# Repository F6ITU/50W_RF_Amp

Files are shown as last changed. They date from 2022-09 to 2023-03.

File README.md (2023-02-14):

# 50W_RF_Amp, Codename Diomedes

Diomedes is a 47 dBm (50W) HF amplifier designed by Manfred XQ6FOD, and intended to be used with any baseband SDR delivering no more than 5 to 10 dBm of  output power between 1 and 54 MHz. 

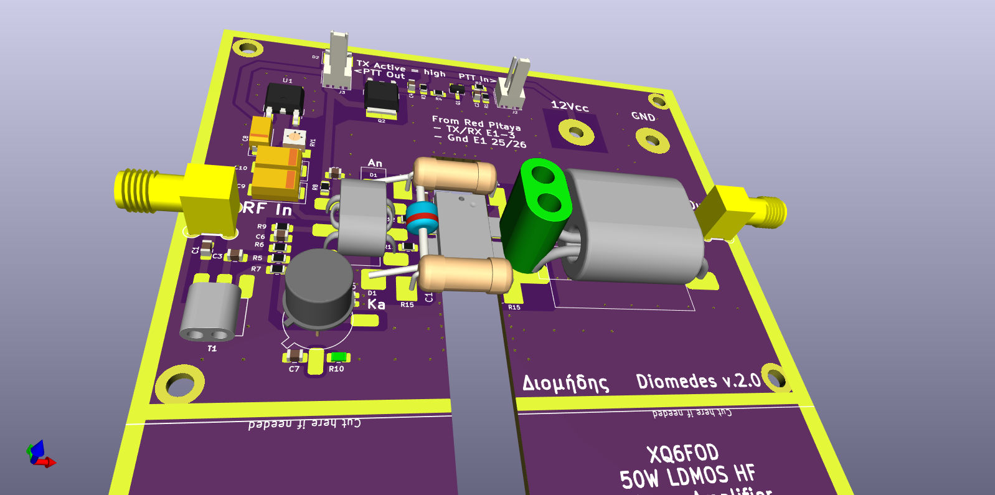
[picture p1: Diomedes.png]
Diomedes, a 50W linear amplifier by XQ6FOD


The original schematic of this project 

https://ludens.cl/Electron/50Wamp/RP50Wampwm.png

as well as the assembly instructions are available at the following URL

https://ludens.cl/Electron/50Wamp/50Wamp.html

This github repository only serves to simplify the work of people who want to build this amplifier. It offers  them the Gerber files and the KiCad implementation of this project.

Thank you, Manfred, for the many developments you’ve done around the Red Pitaya board, and especially for your work on the EER support. It’s a « must read »… at least.

This amplifier is designed to follow a 14 or 16 bit Red Pitaya board or any barefoot DDC/DUC SDR board. It completes the series of devices constituting the Alexiares frontend developed by the OpenHPSDR group

https://wiki.electrolab.fr/Projets:Lab:2017:Peripheriques_Angelia

and replaces advantageously the old and outdated  Pennywhistle linear amplifier 

https://openhpsdr.org/pennywhistle.php

It should be noted that board's dimensions and mounting holes are completely compatible with Pennywhistle physical and mechanical design. In fact, Diomedes has been designed as a substitute amplifier. 
The only major difference is the input allowed power (9 dBm for Diomedes, 27 dBm max for Pennywhistle).

More powerful, more sensitive, less expensive, modern, this final stage uses a tandem of LDMOS transistors. It is perfectly matched with the Alex low pass filter 

https://wiki.electrolab.fr/Projets:Lab:2017:Peripheriques_Angelia#Alexiares_lpf

The code name Diomede was given to this amplifier to match the OpenHPSDR naming scheme. 
Diomedes, hero of the Illiad, was one of the most powerful warrior of the Argian clan, opponent of Apollo the defender of Troy. Apollo is the code name of the very first amplifier and low-pass filter tanddem proposed by the OpenHPSDR 

https://openhpsdr.org/apollo.php

So far, this github project is still under development, as long as the first Diomedes PCB  hasn’t been assembled and tested. Do NOT use these Gerber files for the moment.

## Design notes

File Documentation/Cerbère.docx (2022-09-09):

Cerbère (Κέρϐερος) est le chien tricéphale, gardien des enfers. Ce gardien-là préserve le SDR des démons provenant des secondes, troisièmes et quatrièmes zones de nyquist. C’est un triple filtre passe-bas destiné à tous les transceivers bande de base couvrant de 0,1 à 60 MHz et qui ne possèdent pas déjà ce genre de protection. C’est notamment le cas des cartes Red Pitaya 14 et 16 bits.

Cerbère fait précéder chacune des deux entrées réception (ADC) d’un double filtre Mini Circuits coupant à partir de 50 MHz. Cette cascade garanti une élimination de plus de 70 dB tout signal émis notamment dans la bande 88/108 MHz de la bande broadcast FM ou des émissions de la bande aviation située au-delà de 110 MHz.

La troisième section utilise un filtre LTCC également passe-bas, qui atténue de 50 dB tout produit harmonique au dessus de 52 MHz. Ce composant à peine plus gros qu’un condensateur MLCC 1210 peut encaisser 5W sans problème, et ainsi filtrer le signal de sortie d’un DAC associé à un pré-driver d’émission.

Les captures d’écran suivantes montrent successivement, pour une plage de fréquence couvrant de 1 à 120 MHz, le comportement des filtres réception en impédance (fig « Réception Smith »), en atténuation et en vswr (fig. « Réception Amplitude ») et enfin la courbe d’amplitude « gain/vswr » du filtre d’émission (fig. « Emission »)

Ressources

Le schéma, le dessin du PCB au format KiCad, les différentes feuilles de caractéristiques des deux composants principaux sont disponibles sur le dépôt github

https://github.com/F6ITU/antialiasing_filter

BOM

Bien que peu utile, (trois références de composants seulement) la BOM interactive peut être téléchargée depuis le lien

https://github.com/F6ITU/antialiasing_filter/blob/main/Documentation/ibom.html

Réalisation

Le montage du boitier GP731 (filtre réception RLP-50+) demande un peu d’attention.

- Badigeonnez l’empreinte du circuit imprimé avec une légère couche de flux
- Positionnez le filtre dans l’alignement du microstrip. Attention, le signal entre et sort des broches 2 et 6, les broches 1, 3, 4, 5, 7 et 8 étant reliées à la masse.
- Déposez un point de brasure sur l’un des contacts de masse 4 ou 8 (contacts latéraux) en veillant à l’alignement général. Il est possible d’utiliser les « via » du pcb comme repères de positionnement (Fg 1)
- Vérifiez l’alignement des contacts 2 et 6, retouchez éventuellement l’orientation du composant en chauffant le point de brasure réalisé précédemment.
- Ancrez le composant en déposant un point de soudure sur le contact de masse diamétralement opposé
- Achevez en soudant les 6 autres points de brasure, en prenant garde de ne pas créer de « pont » entre le microstrip « signal » et la masse.

Répétez l’opération pour les trois autres filtres RLP-50+

Le montage du filtre émission LFCV-52+ est légèrement différent.

- Badigeonnez l’empreinte du circuit imprimé avec une légère couche de flux
- Positionnez le filtre dans l’alignement du microstrip.
- Déposez un point de brasure sur l’un des contacts « Signal » (et surtout pas les contacts de masse latéraux).
- Vérifiez l’alignement du contact signal opposé, corrigez éventuellement la coaxialité du composant avec le microstrip en chauffant le point de brasure réalisé précédemment.
- Ancrez le composant en déposant un point de soudure sur le contact « signal » diamétralement opposé
- Achevez en soudant les 2 autres points de brasure sur les faces latérale (GND).
- Installez et soudez les 6 connecteurs SMA femelle
- Reliez Cerbère aux ports 1 à 3 de la carte Red Pitaya

En réception, la réjection hors bande sur les portions stratégiques du spectre (bande FM, bande aviation…) se situe entre 80 et 90 dB. L’adaptation d’impédance « in band » demeure dans l’immédiat voisinage des 50 Ohms.

A l’émission (LFCV-52+), H3 à 50 MHz est à -32 dB, mais seulement à -3 dB pour H3 à 30 MHz. C’est donc un filtre assez « mou » mais pouvant être installé après le premier driver. Il vient donc assister les autres systèmes de filtrage (lpf émission, mécanisme de pré-distorsion) et minimise de 3 à 30 dB les risques d’émissions indésirables dans la secondes zone de nyquist et au-delà.

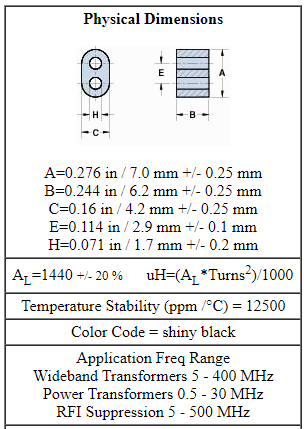
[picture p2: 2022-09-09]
Documentation/BN43-2402.png

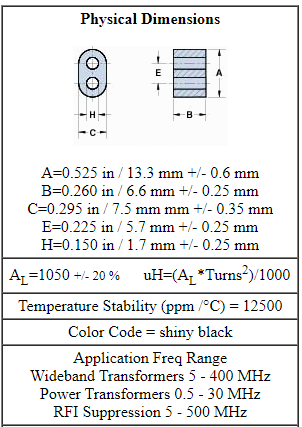
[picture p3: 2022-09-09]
Documentation/BN43-1502.png

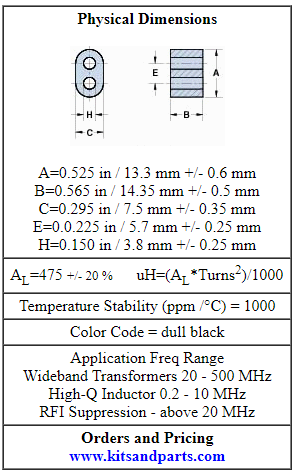
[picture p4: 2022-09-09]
Documentation/BN61-202.png

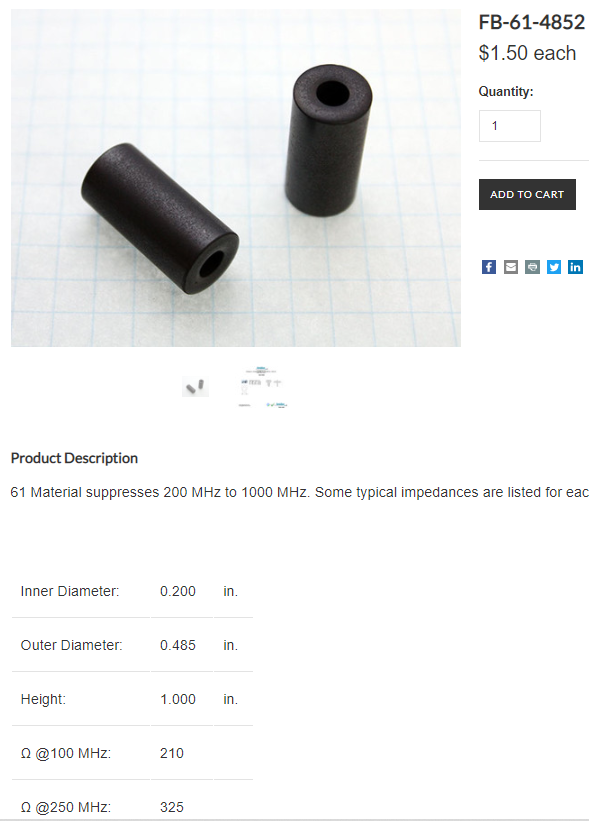
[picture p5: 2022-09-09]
Documentation/FB-61-4852.png

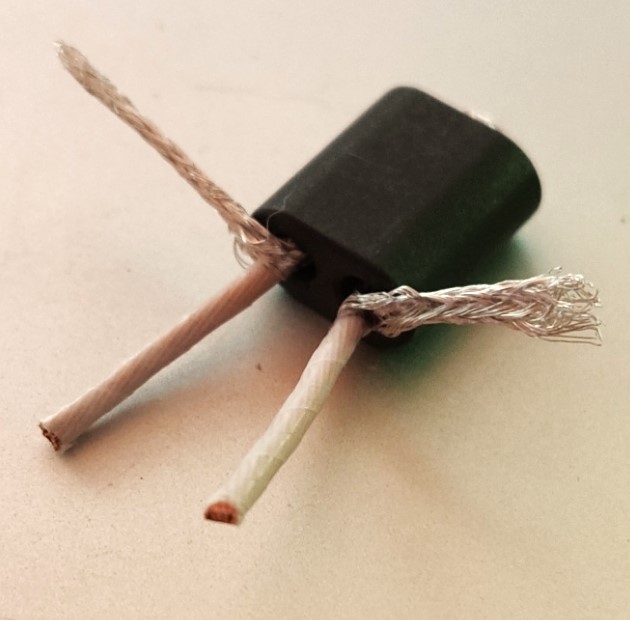
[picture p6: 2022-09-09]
Documentation/transfo.jpg

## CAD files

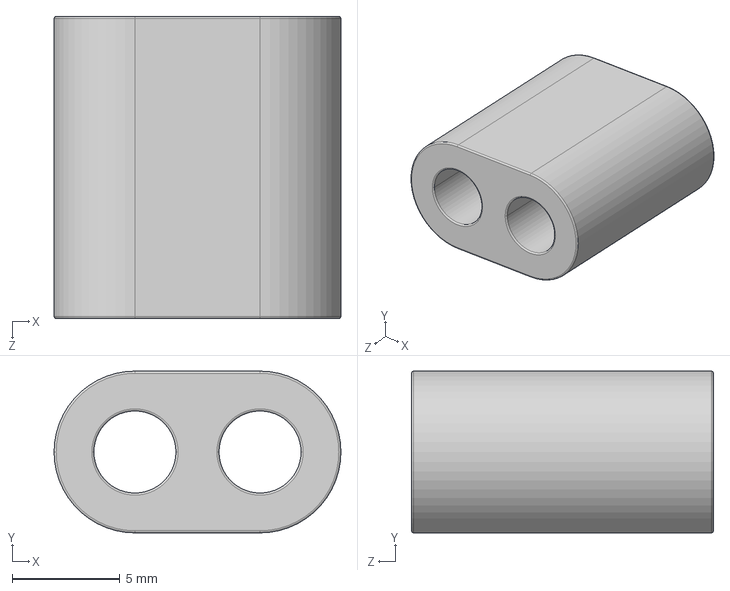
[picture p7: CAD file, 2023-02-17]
Symboles/BN 73-202.STEP
13.3 x 7.50 x 14.0 mm

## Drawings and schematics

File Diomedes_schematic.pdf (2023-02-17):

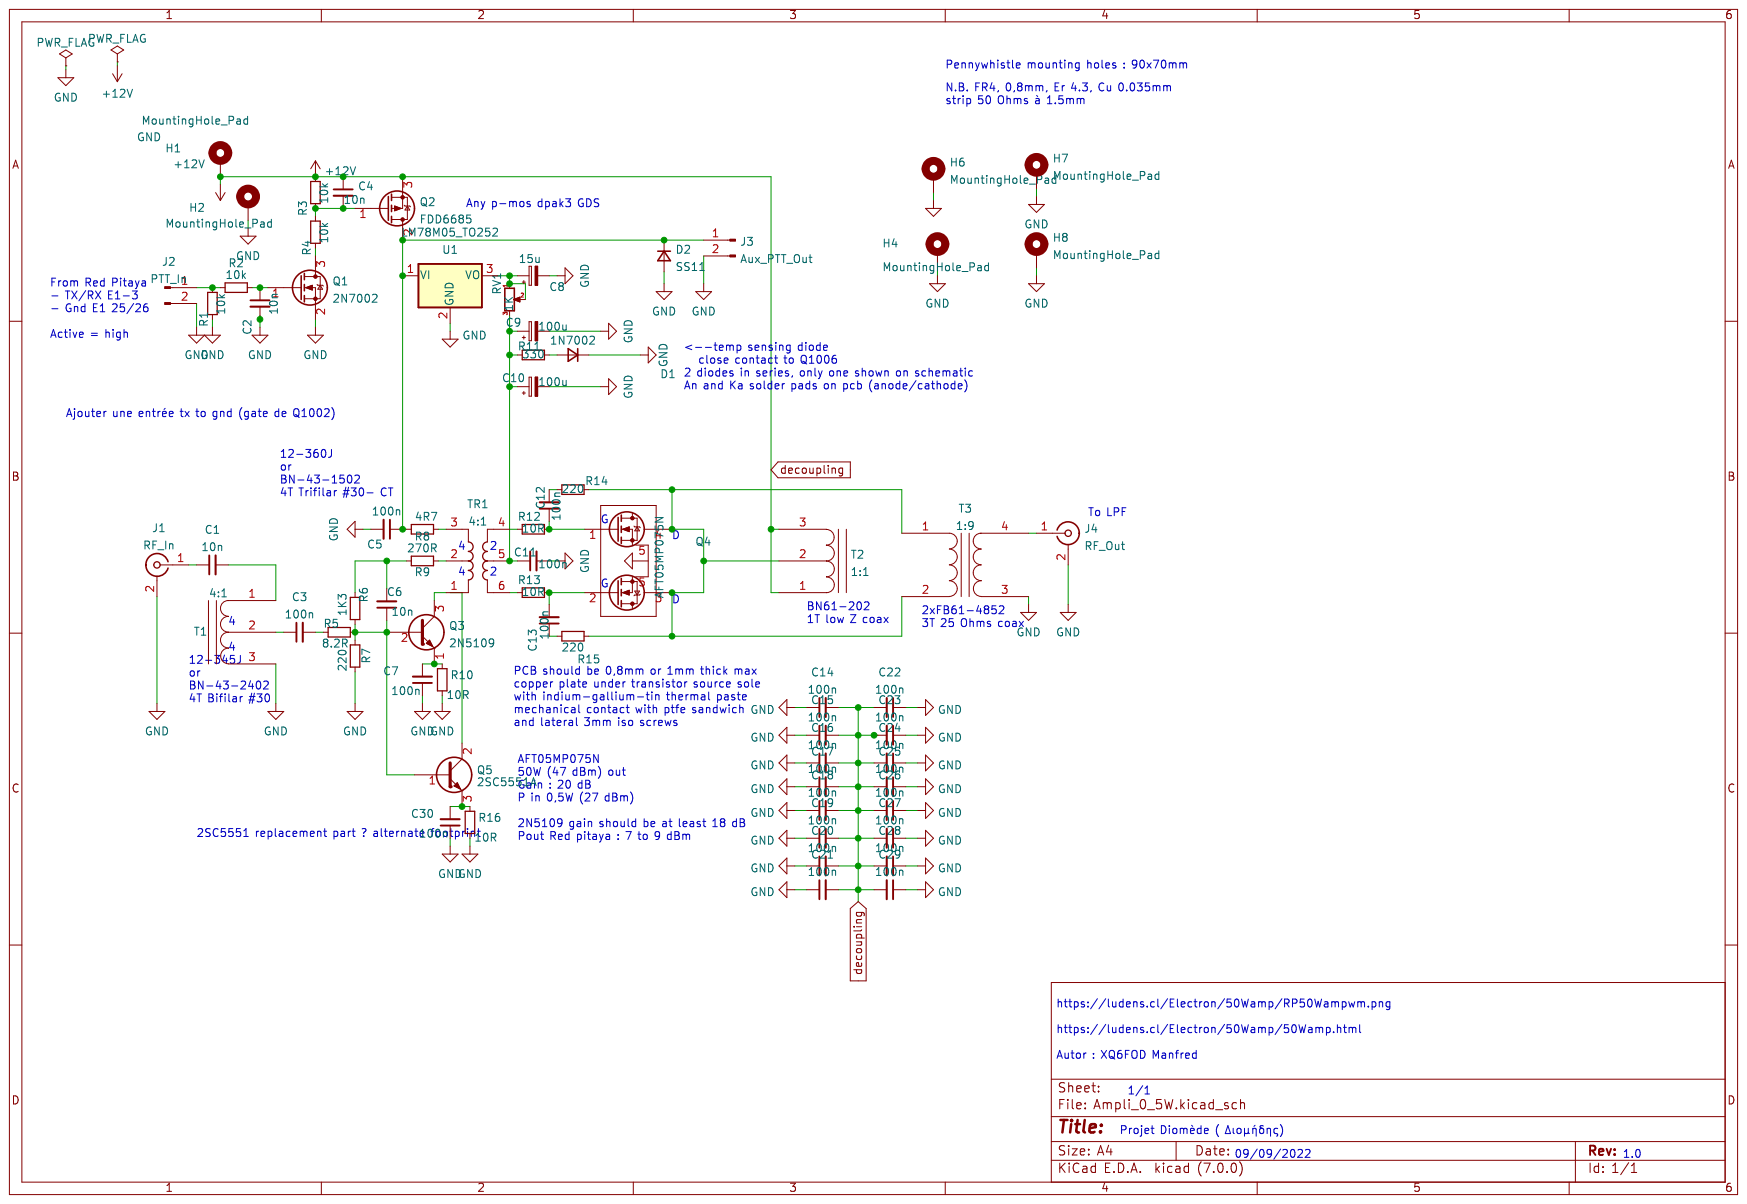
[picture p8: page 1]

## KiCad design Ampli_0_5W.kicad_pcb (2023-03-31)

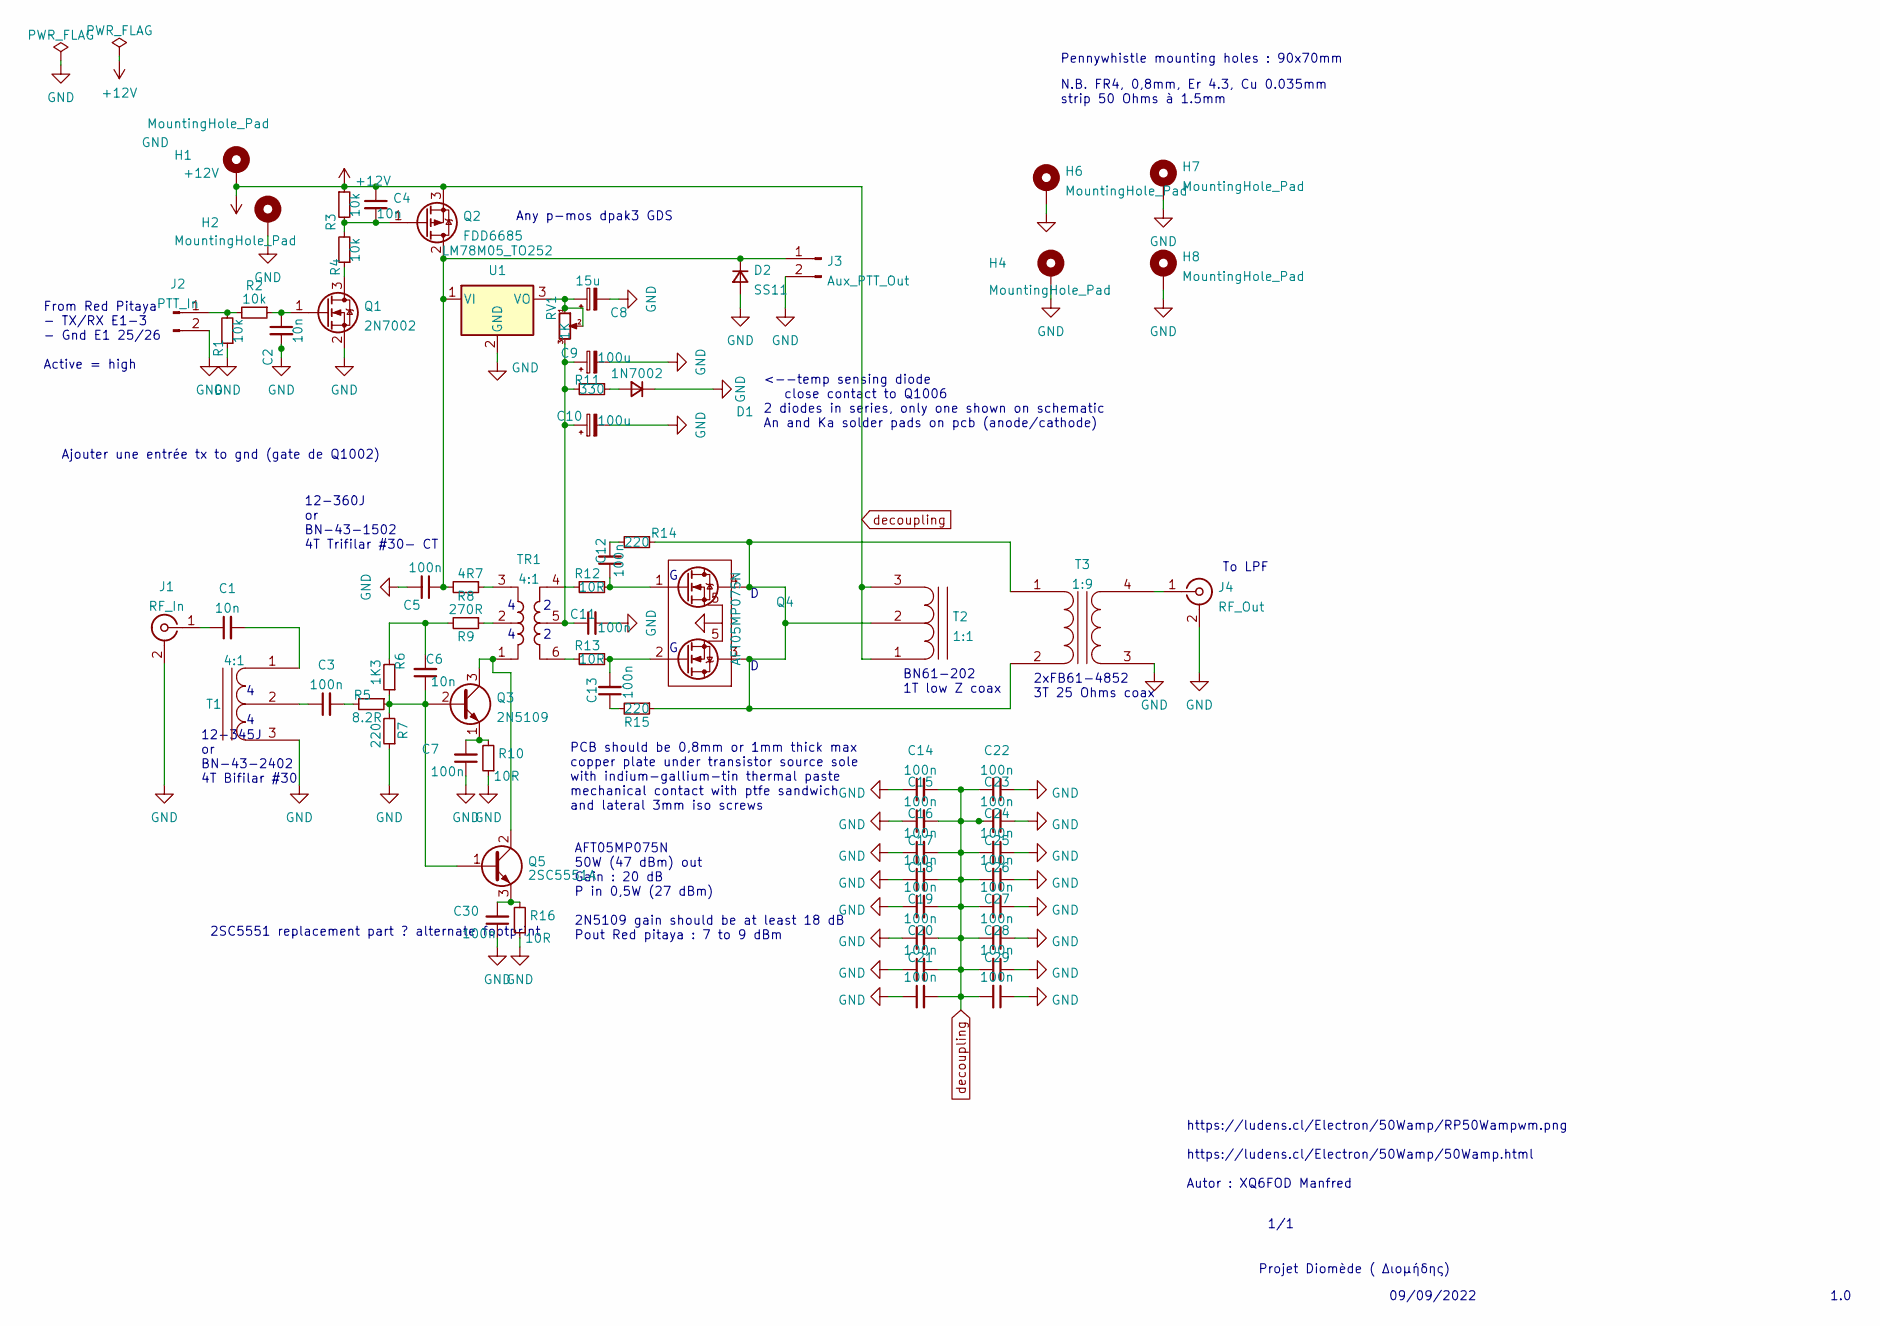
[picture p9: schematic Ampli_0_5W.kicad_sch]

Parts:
C1, C2, C4, C6: 10n; C_0805_2012Metric_Pad1.18x1.45mm_HandSolder
C3, C5, C7, C11: 100n; C_0805_2012Metric_Pad1.18x1.45mm_HandSolder
C8: 15u; CP_EIA-6032-28_Kemet-C_Pad2.25x2.35mm_HandSolder
C9, C10: 100u; CP_EIA-7343-31_Kemet-D_Pad2.25x2.55mm_HandSolder
C12, C13: 100n; C_1206_3216Metric_Pad1.33x1.80mm_HandSolder
C14, C15, C16, C17, C18, C19, C20, C21, C22, C23, C24, C25, C26, C27, C28, C29: 100n; C_1210_3225Metric_Pad1.33x2.70mm_HandSolder
C30: 100n; C_0603_1608Metric_Pad1.08x0.95mm_HandSolder
D1: 1N7002; D_2114_3652Metric_Pad1.85x3.75mm_HandSolder
D2: SS11; D_1812_4532Metric_Pad1.30x3.40mm_HandSolder
H1, H2, H4, H6, H7, H8: MountingHole_Pad; MountingHole_3.2mm_M3_DIN965_Pad
J1: RF_In; SMA_PINS
J2: PTT_In; Molex_KK-254_AE-6410-02A_1x02_P2.54mm_Vertical
J3: Aux_PTT_Out; Molex_KK-254_AE-6410-02A_1x02_P2.54mm_Vertical
J4: RF_Out; SMA_PINS
Q1: 2N7002; SOT-23_Handsoldering
Q2: FDD6685; TO-252-2
Q3: 2N5109; TO-39-3
Q4: AFT05MP075N
Q5: 2SC5551A; SOT-89-3
R1, R2, R3, R4: 10k; R_0805_2012Metric_Pad1.20x1.40mm_HandSolder
R5: 8.2R; R_0805_2012Metric_Pad1.20x1.40mm_HandSolder
R6: 1K3; R_0805_2012Metric_Pad1.20x1.40mm_HandSolder
R7: 220; R_0805_2012Metric_Pad1.20x1.40mm_HandSolder
R8: 4R7; R_0805_2012Metric_Pad1.20x1.40mm_HandSolder
R9: 270R; R_0805_2012Metric_Pad1.20x1.40mm_HandSolder
R10, R12, R13: 10R; R_0805_2012Metric_Pad1.20x1.40mm_HandSolder
R11: 330; R_0805_2012Metric_Pad1.20x1.40mm_HandSolder
R14, R15: 220; R_2816_7142Metric_Pad3.20x4.45mm_HandSolder
R16: 10R; R_0603_1608Metric_Pad0.98x0.95mm_HandSolder
RV1: 1K; Potentiometer_Bourns_TC33X_Vertical
T1: 4:1; BN-43-2402
T2: 1:1; BN-61-202
T3: 1:9; Dual_FB-61-4852
TR1: 4:1; BN-43-1502
U1: LM78M05_TO252; TO-252-2

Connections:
GND: C2.2, C5.2, C7.1, C8.2, C9.2, C10.2, C11.2, C14.1, C15.1, C16.1, C17.1, C18.1, C19.1, C20.1, C21.1, C22.1, C23.1, C24.1, C25.1, C26.1, C27.1, C28.1, C29.1, C30.1, D1.1 (K), D2.2 (A), H2.1, H4.1, H6.1, H7.1, H8.1, J1.2 (Ext), J2.2, J3.2, J4.2 (Ext), Q1.2 (S), R1.1, R7.1, R10.1, R16.1, T1.3 (SC), T3.3 (SA), U1.2 (GND)
unnamed: C3.2, R5.2
unnamed: C6.2, R6.2, R9.2
unnamed: C9.1, C10.1, C11.1, R11.2, RV1.3, TR1.5
unnamed: C12.1, Q4.1 (G), R12.1
unnamed: C12.2, R14.2
unnamed: C13.1, R15.2
unnamed: C13.2, Q4.2 (G), R13.1
unnamed: D1.2 (A), R11.1
unnamed: C5.1, D2.1 (K), J3.1, Q2.2 (D), R8.2, U1.1 (VI)
unnamed: C1.1, J1.1 (In)
unnamed: J2.1, R1.2, R2.2
unnamed: J4.1 (In), T3.4 (SB)
unnamed: Q1.3 (D), R4.1
unnamed: C2.1, Q1.1 (G), R2.1
unnamed: C4.2, Q2.1 (G), R3.2, R4.2
unnamed: C6.1, Q3.2 (B), Q5.1 (B), R5.1, R6.1, R7.2
unnamed: Q3.3 (C), Q5.2 (C), TR1.1
unnamed: C7.2, Q3.1 (E), R10.2
unnamed: C30.2, Q5.3 (E), R16.2
unnamed: R8.1, TR1.3
unnamed: R9.1, TR1.2
unnamed: R12.2, TR1.4
unnamed: R13.2, TR1.6
unnamed: C1.2, T1.1 (SA)
unnamed: C3.1, T1.2 (SB)
unnamed: Q4.3 (D), Q4.4 (D), R14.1, R15.1, T2.2 (SB), T3.1 (AA), T3.2 (AB)
unnamed: C8.1, RV1.1, RV1.2, U1.3 (VO)
decoupling: C4.1, C14.2, C15.2, C16.2, C17.2, C18.2, C19.2, C20.2, C21.2, C22.2, C23.2, C24.2, C25.2, C26.2, C27.2, C28.2, C29.2, H1.1, Q2.3 (S), R3.1, T2.1 (SA), T2.3 (SC)

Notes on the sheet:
To LPF
4 4
12-360J or BN-43-1502 4T Trifilar #30- CT
09/09/2022
Projet Diomède ( Διομήδης)
BN61-202 1T low Z coax
AFT05MP075N 50W (47 dBm) out Gain : 20 dB P in 0,5W (27 dBm) 2N5109 gain should be at least 18 dB Pout Red pitaya : 7 to 9 dBm
Pennywhistle mounting holes : 90x70mm
2xFB61-4852 3T 25 Ohms coax
2SC5551 replacement part ? alternate footprint
N.B. FR4, 0,8mm, Er 4.3, Cu 0.035mm strip 50 Ohms à 1.5mm
12-345J or BN-43-2402 4T Bifilar #30
PCB should be 0,8mm or 1mm thick max copper plate under transistor source sole with indium-gallium-tin thermal paste mechanical contact with ptfe sandwich and lateral 3mm iso screws
Ajouter une entrée tx to gnd (gate de Q1002)
1/1
https://ludens.cl/Electron/50Wamp/RP50Wampwm.png https://ludens.cl/Electron/50Wamp/50Wamp.html Autor : XQ6FOD Manfred
2 2
Any p-mos dpak3 GDS
From Red Pitaya - TX/RX E1-3 - Gnd E1 25/26 Active = high
D D
<--temp sensing diode close contact to Q1006 2 diodes in series, only one shown on schematic An and Ka solder pads on pcb (anode/cathode)
1.0
G G

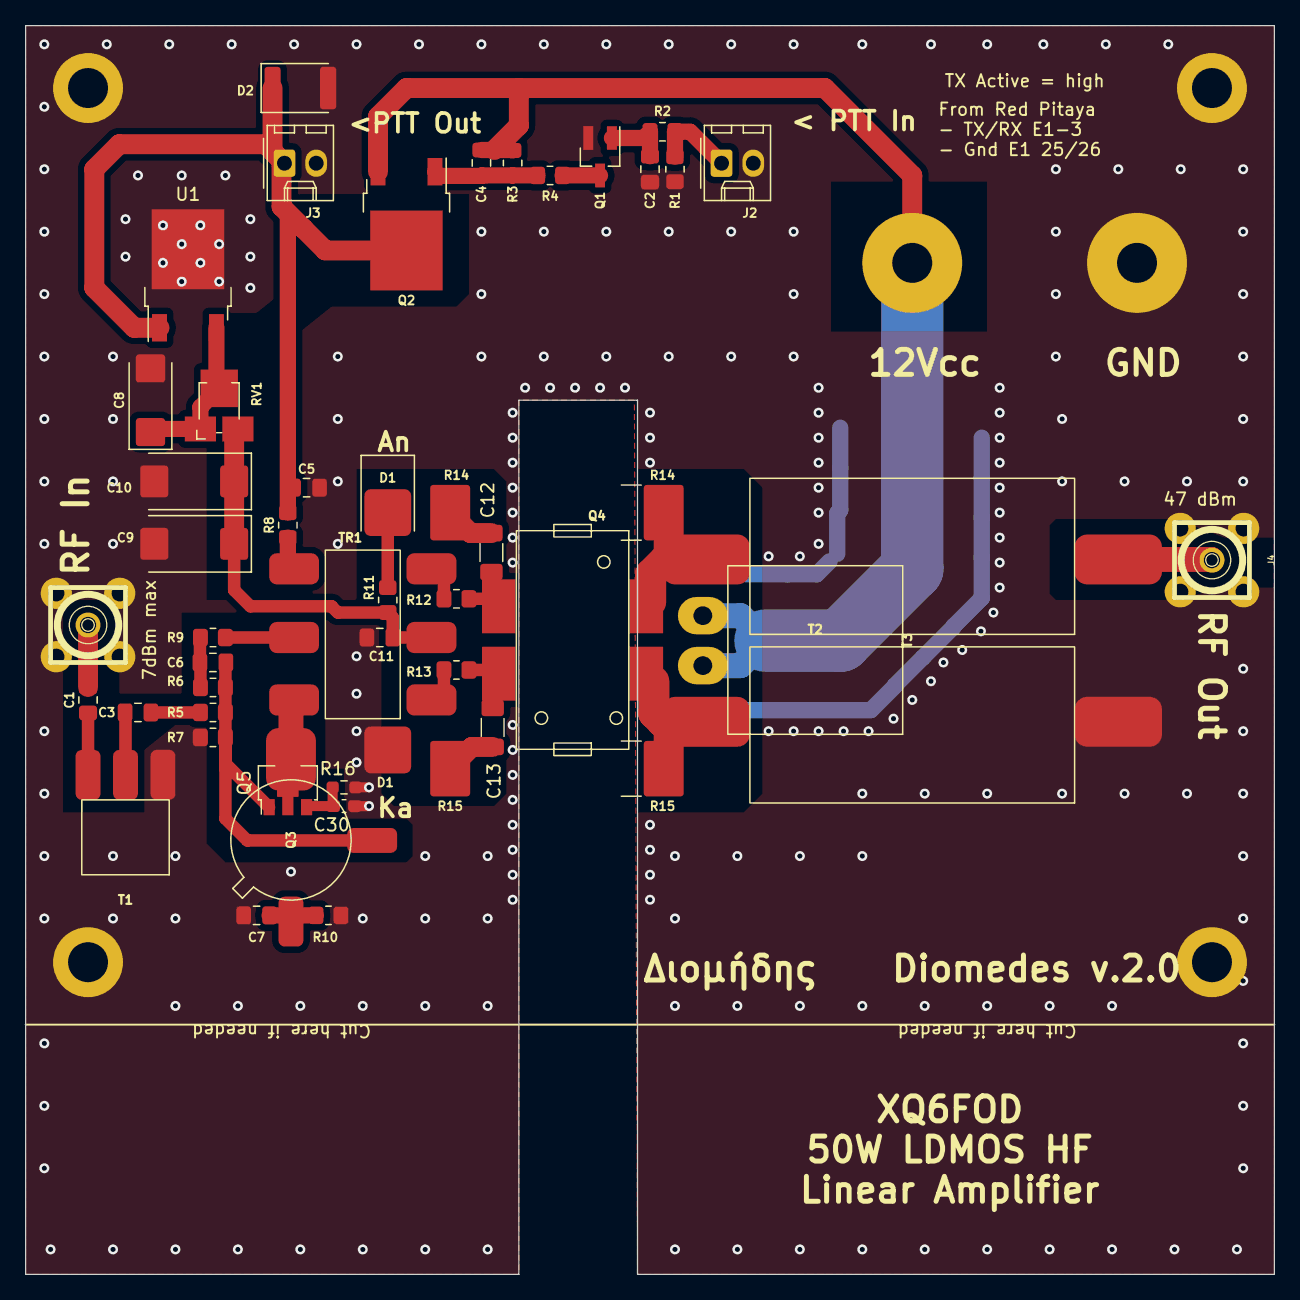
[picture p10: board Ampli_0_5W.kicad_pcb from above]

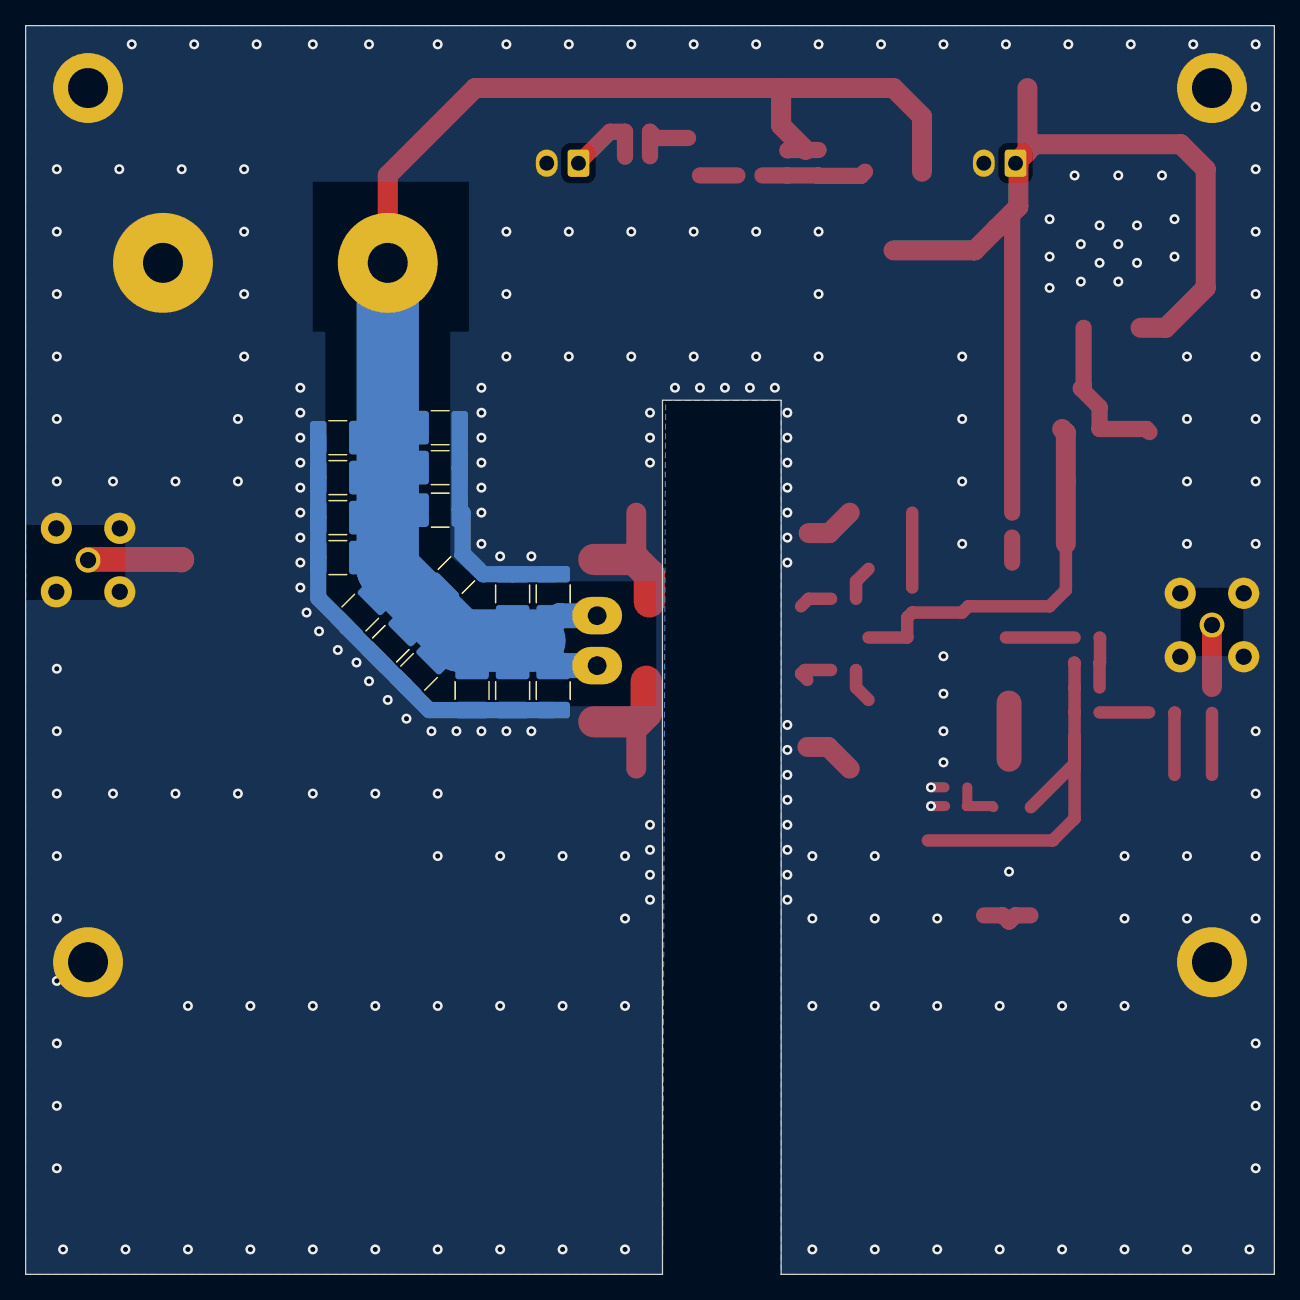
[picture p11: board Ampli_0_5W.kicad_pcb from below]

Board: 2 copper layers, 100.0 x 100.0 mm, 69 parts (16 on the bottom side), 29 nets.

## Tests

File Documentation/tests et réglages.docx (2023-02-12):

https://ludens.cl/Electron/50Wamp/RP50Wampwm.png

https://ludens.cl/Electron/50Wamp/50Wamp.html

Autor : XQ6FOD Manfred

J'ai utilisé des multimètres numériques pour mesurer la tension et le courant d'alimentation. Un oscilloscope Tektronix 485 avec soit une connexion directe 50Ω à travers des atténuateurs, soit en utilisant des sondes Z0 à faible impédance ayant une bande passante de plus de 500MHz, pour voir les formes d'onde et mesurer la puissance de sortie. Et l'affichage spectral de PowerSDR, dérivé par le récepteur #2 du diviseur de tension de retour, pour évaluer la linéarité par la mesure de l'IMD. L'analyseur d'amplificateur à prédistorsion adaptative du logiciel a été utilisé pour mesurer et représenter graphiquement séparément la linéarité d'amplitude et de phase. La charge fictive de 50Ω utilisée est une unité Bird évaluée jusqu'à UHF.

Tous les résultats de mesure concernent l'amplificateur complet, y compris l'étage d'attaque. Le pilote, le relais, le circuit de commutation et le circuit de polarisation tirent un total de 120mA, de sorte que le courant dans l'étage final est toujours inférieur de 0,12A au courant total.

Sur la bande 40m, en utilisant le filtre passe-bas 40m, une alimentation de 13,8V, et avec la polarisation réglée pour un courant total de 1,12A à vide (1A dans l'étage final), l'amplificateur commence juste à compresser le gain à 50W de sortie. Ces courbes montrent la réponse de l'amplificateur dans ces conditions. La courbe bleue est la réponse en amplitude, et la courbe jaune montre la réponse en phase. Les deux autres courbes sont les compléments de celles-ci, et montrent les corrections que le système de prédistorsion adaptatif appliquera s'il est activé.

Comme vous pouvez le voir, la courbe de gain est assez linéaire, mais pas parfaitement, montrant le gain le plus faible à environ un tiers de l'amplitude maximale, et le gain le plus élevé à un peu moins de la pleine puissance. Ce type de distorsion est inévitable, étant donné que les MOSFET sont des dispositifs à loi carrée, plutôt que linéaires. Nous pourrions éliminer la légère non-linéarité à l'extrémité supérieure de la gamme d'entraînement, en limitant l'amplificateur à 45W, ou en augmentant légèrement la tension d'alimentation, mais la distorsion dans la gamme de faible puissance est simplement un fait de la vie. Nous pouvons la réduire, en augmentant encore la polarisation et en utilisant une rétroaction négative encore plus forte, mais jamais l'éliminer.

La réponse en phase montre un déphasage d'environ 6° entre la faible puissance et le maximum. Cela vient principalement des capacités variables en tension que tous les transistors ont, et nous ne pouvons pas faire grand chose à ce sujet, sauf choisir des transistors qui ont de faibles capacités, ce que j'ai fait.

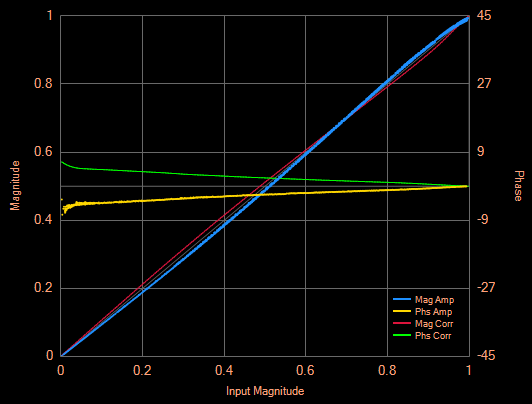
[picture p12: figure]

Le signal bicolore semble assez propre et agréable sur l'écran de l'oscilloscope. Il faudrait un œil très exercé pour détecter la légère distorsion d'amplitude de cet amplificateur sur l'oscilloscope ! Et bien sûr, l'oscilloscope ne peut pas du tout montrer la distorsion de phase.

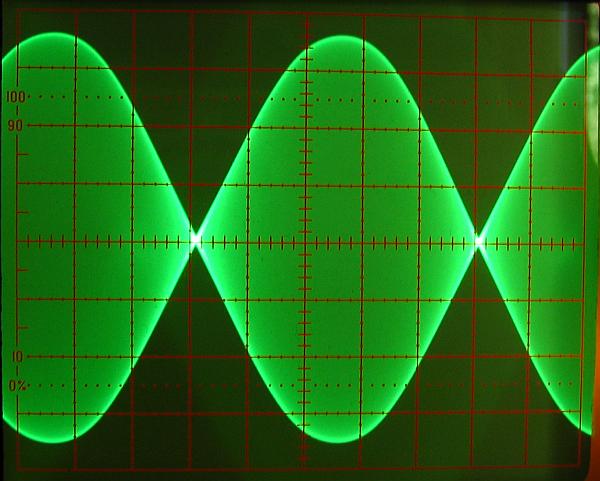
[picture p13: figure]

L'analyseur de spectre est le meilleur outil pour évaluer la linéarité. Vous pouvez voir que les produits d'intermodulation de troisième ordre sont approximativement 34 ou 35 dB en dessous des tonalités individuelles, ce qui signifie qu'ils sont 40 à 41 dB en dessous de la sortie PEP. C'est bien mieux que ce que de nombreux émetteurs-récepteurs commerciaux atteignent !

La DMI de 5e ordre n'est que légèrement inférieure, mais les produits de DMI plus élevés perdent de leur force assez rapidement.

Dans ces conditions, l'amplificateur complet consomme 3,74A. A 50W de sortie monotone (porteuse), il consomme 5,57A. Cela représente un rendement à tonalité unique de 65% pour l'amplificateur complet, y compris le pilote et la commutation, ou 66,5% pour l'étage final seul.

La limite théorique des amplificateurs de classe B pure est de 78,5 %, mais dans les amplificateurs réels, elle est toujours inférieure en raison de la saturation imparfaite des transistors et de diverses autres pertes. La classe AB réduit encore le rendement. Le rendement de ce petit amplificateur est donc probablement aussi bon qu'on peut l'espérer !

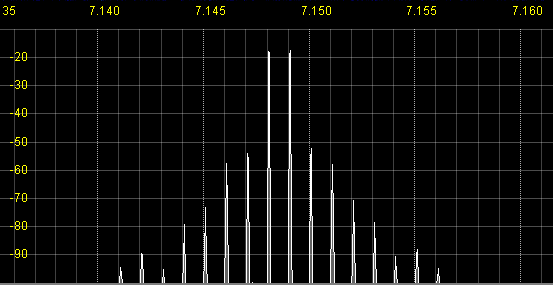
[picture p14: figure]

Bien que cet amplificateur soit suffisamment propre pour être diffusé sans aucun artifice numérique, il n'y a aucune raison pour que je n'utilise pas certains des artifices offerts par le traitement moderne des signaux numériques. Parmi celles-ci, la prédistorsion adaptative. En l'activant, la 3ème IMD chute à 53dB en dessous de chaque tonalité, 59dB en dessous de la PEP, et tous les autres produits IMD sont réduits d'au moins 10dB supplémentaires ! La sortie PEP augmente de façon à peine perceptible, et le courant d'alimentation total augmente marginalement à 3,79A.

Tous les produits IMD ne diminuent pas, cependant. Les plus éloignés, à commencer par le 11ème, augmentent en fait en force, par rapport au résultat non déformé. C'est un effet secondaire typique de la prédistorsion dans le traitement numérique, causé principalement par la bande passante limitée sur laquelle le système de prédistorsion analyse et corrige les non-linéarités de l'amplificateur. Mais comme tous ces produits IMD indésirables se situent bien au-delà de 60 dB en dessous de la PEP, ce n'est pas un problème dans la plupart des applications pratiques pour les amateurs.

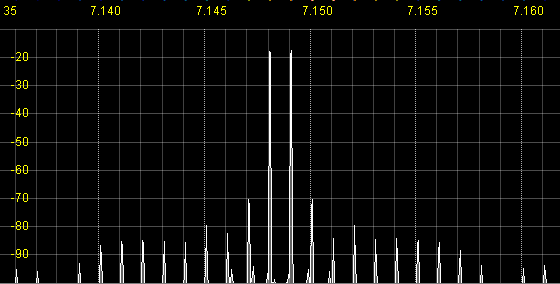
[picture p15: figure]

Avec le système de prédistorsion adaptatif à ma disposition, il est bien sûr tentant d'améliorer le rendement et la puissance de sortie de l'amplificateur, en détériorant sa linéarité dans le processus, puis de réparer la linéarité par la magie numérique. Pour essayer ceci, j'ai réduit le réglage de la polarisation pour obtenir seulement 0,5A de courant total à l'absence de signal, ce qui signifie 380mA de courant de repos dans l'étage final, et ensuite le piloter plus fortement, jusqu'à une compression de gain assez profonde.

Comme il s'agit d'un amplificateur push-pull de classe AB, qui écrête la tension de sortie lorsqu'il est suralimenté, la compression de gain est plutôt dure et abrupte, il n'y a donc qu'une modeste quantité de puissance à gagner en fonctionnant en saturation. J'ai obtenu 61W de sortie en faisant fonctionner l'amplificateur de cette manière.

La courbe de gain montre une forte compression à haute puissance, et une distorsion assez sévère du crossover causée par la faible polarisation. La courbe de réponse en phase ne change pas beaucoup, il y a juste un peu plus de changement de phase dans la région de saturation, causé par les drains se rapprochant du potentiel de masse pour une plus grande partie du cycle RF. A la tension de drain la plus basse, la modulation de capacité est la plus grande.

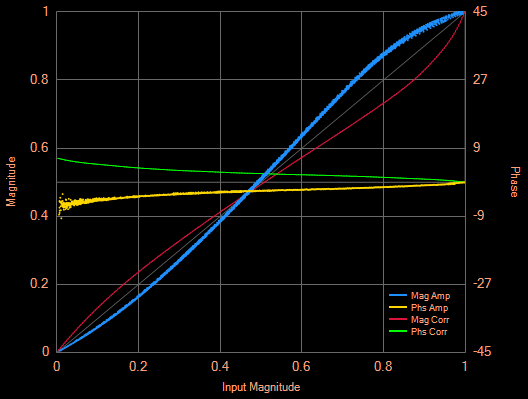
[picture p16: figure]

La forme d'onde sur l'écran de l'oscilloscope montre la distorsion du filtre et le plafonnement de manière très évidente. Il est facile de voir la courbe de réponse d'amplitude déformée modulant l'enveloppe sinusoïdale !

A quel point un tel signal est-il sale ?

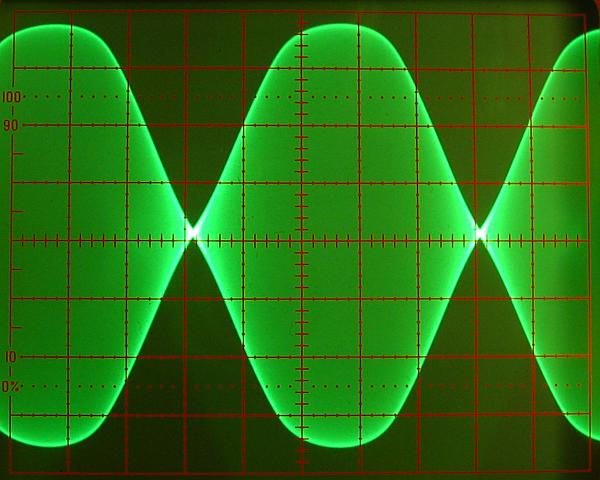
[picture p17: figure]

L'analyseur de spectre fournit la réponse : Beaucoup plus sale ! Mais bien assez bon pour certaines personnes...

Le 5ème IMD finit par être plus grand que le 3ème, à environ 28dB en dessous de chaque ton. Des spécialistes sournois voulant vendre un amplificateur qui fonctionne normalement comme ceci pourraient vous dire fièrement que la 3ème IMD est de 35dB en dessous, sans vous dire que la 5ème IMD est seulement de 28dB en dessous !

La plupart des fabricants sont pleinement satisfaits d'un tel résultat, et de nombreux émetteurs-récepteurs disponibles dans le commerce ne peuvent pas faire mieux que cela lorsqu'ils sont alimentés à leur pleine puissance ! Surtout à une tension d'alimentation inférieure à la normale.

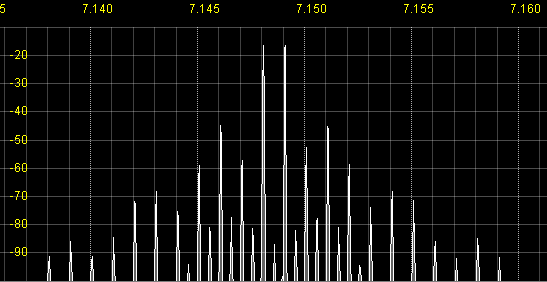
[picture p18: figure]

En utilisant PowerSDR, je peux. Vous le pouvez aussi, si vous l'utilisez. L'activation de la prédistorsion adaptative fait descendre les produits IMD là où ils doivent être ! La 3ème IMD est en baisse d'environ 52dB sous chaque ton, à peine 1dB de moins qu'à 50W avec une forte polarisation !

En fonctionnant ainsi, avec la prédistorsion, l'amplificateur produit un signal très propre de 61W, tout en consommant 4.03A pendant la transmission de 2 tons, et 5.97A quand il transmet un seul ton (porteur). Et cela, chers amis, représente un rendement global de 74%, incluant l'étage d'attaque, le relais et le circuit de commutation ! Ou 75,6 % si l'on ne mesure que la consommation de courant de l'étage final, mais je ne mettrai pas ma main au feu pour les décimales, étant donné que je mesure la puissance sur un écran d'oscilloscope. Bien que mon oscilloscope soit de haute qualité, très bien calibré, et qu'il produise une trace bien nette, la mesure analogique a ses limites...

Obtenir ~75% d'efficacité d'un amplificateur de classe AB très simple, avec un signal très propre, est une publicité forte pour la prédistorsion adaptative et pour la conception d'amplificateurs propres.

J'ai essayé d'aller plus loin, en diminuant encore plus la polarisation, en pilotant l'amplificateur encore plus fort, et en laissant la prédistorsion adaptative nettoyer le désordre résultant. Mais les résultats n'ont pas été aussi bons, car la faible polarisation a fait augmenter les produits IMD extrêmes, et ceux-ci sont hors du contrôle du système de prédistorsion adaptative à bande passante limitée. Il ne peut faire de la magie que jusqu'à un certain point... J'en ai donc conclu que faire fonctionner l'amplificateur comme montré ici, à un peu plus de 60W et avec un courant total de 0,5A à zéro signal, et en utilisant la prédistorsion adaptative, est à peu près le mieux. Et pour les personnes qui n'ont pas un système de génération de signal qui inclut la prédistorsion adaptative, je suggère de garder le réglage de polarisation à environ 1,1 à 1,3A de courant total à zéro signal, et de limiter la puissance de sortie à 50W.

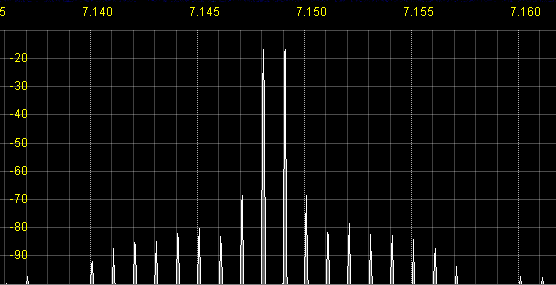
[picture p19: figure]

Rien n'a été dit jusqu'à présent sur les harmoniques, car grâce à l'utilisation d'un filtre passe-bas décent, elles ne sont pas un problème. Mais je les ai rapidement mesurées. En faisant fonctionner l'amplificateur à 61W de sortie, la deuxième harmonique est 54dB en dessous de la fondamentale, la troisième est 63dB en dessous, la quatrième est 77dB en dessous, et la cinquième est 74dB en dessous. Les amplificateurs push-pull suppriment les harmoniques paires auto-générées, s'ils sont bien équilibrés, mais bien sûr ils amplifient volontiers toute harmonique qui pourrait être présente dans le signal de commande ! Et mon étage d'attaque est asymétrique, donc la seconde harmonique est la plus forte. De plus, le Red Pitaya peut avoir un contenu harmonique significatif dans sa sortie. Ce sont les raisons pour lesquelles la deuxième harmonique est de loin la plus forte. Combiné avec le fait, bien sûr, que les filtres passe-bas atténuent plus fortement les harmoniques supérieurs.

Si une application rigoureuse exigeait une suppression plus forte de la seconde harmonique, j'essaierais un étage d'attaque push-pull.

Dans les amplificateurs RF à large bande, la forme d'onde de tension au niveau du drain révèle généralement des imperfections si graves que de nombreux constructeurs préfèrent ne pas la regarder ! Comme je semble avoir des penchants masochistes, du moins dans le domaine de l'électronique, je le fais.

A une puissance de sortie d'environ 20W, il ressemble à ce qui est montré ici. L'échelle verticale est de 5V/div, et le centre de l'écran est à la tension d'alimentation de 13,8V. Comme vous pouvez le voir, la forme d'onde ressemble beaucoup à une onde sinusoïdale, à l'exception d'une ondulation au moment du passage à zéro, lorsque le transistor cesse d'être en conduction. Ceci est causé par les fuites non nulles et l'inductance parasite dans le transformateur d'alimentation et le circuit associé. J'ai eu beau essayer de réduire ces inductances indésirables, il reste quelques dizaines de nanohenry, et à la faible charge de drain d'à peine 1,4Ω du côté actif, c'est assez mauvais.

Même avec ce déhanchement, cette forme d'onde est bien meilleure que ce que vous verrez dans de nombreux autres amplificateurs push-pull.

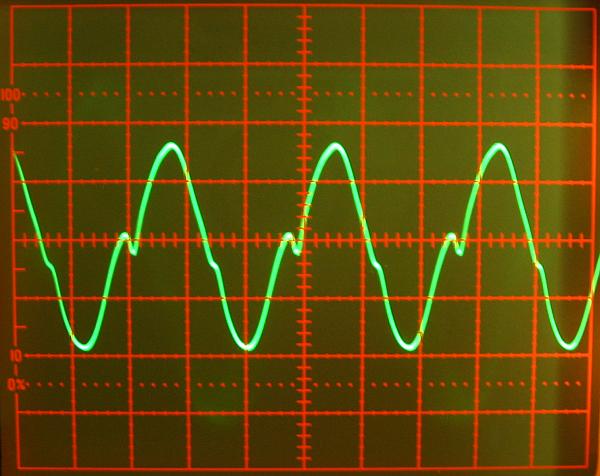
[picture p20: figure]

A 61W de sortie, l'amplificateur est fortement saturé. Vous pouvez voir le LDMOSFET tirer son drain très près de la masse, environ 0.5V (rappelez-vous que la ligne centrale est 13.8V et que l'échelle est 5V/div).

L'ondulation est toujours présente et plus importante, en raison du courant de drain plus élevé.

On peut également voir que le couplage entre les drains est présent mais loin d'être parfait. S'il était parfait, la forme d'onde serait symétrique. Mais le haut de la forme d'onde montre une rampe au lieu d'une ligne horizontale alors que le transistor opposé maintient son drain à la masse, ce qui est à nouveau causé par les inductances parasites et de fuite. Au moins, le couplage est assez bon pour éviter totalement le dépassement de tension. La tension de pointe du drain est un peu moins de deux fois la tension d'alimentation, exactement comme cela devrait être le cas dans un amplificateur de classe AB.

Et comme l'inductance de fuite est découplée entre les côtés, l'ondulation d'un côté ne se transfère pas à l'autre. Au lieu de cela, il y a une secousse séparée, plus petite, sur la pente descendante, causée par l'augmentation du courant de drain et l'inductance de fuite.

Dans le domaine spectral, ces secousses apparaissent comme des harmoniques, et sont assez bien rejetées par le filtre passe-bas.

Donc, mon transformateur d'alimentation fabriqué avec amour et mon retour à la terre à très faible inductance sont encore assez mauvais pour causer un couplage drain-drain manifestement imparfait, même sur 40 mètres ! Alors que la fondamentale 7MHz est bien couplée, les harmoniques ne le sont pas. Sur les bandes supérieures, cela ne peut qu'empirer.

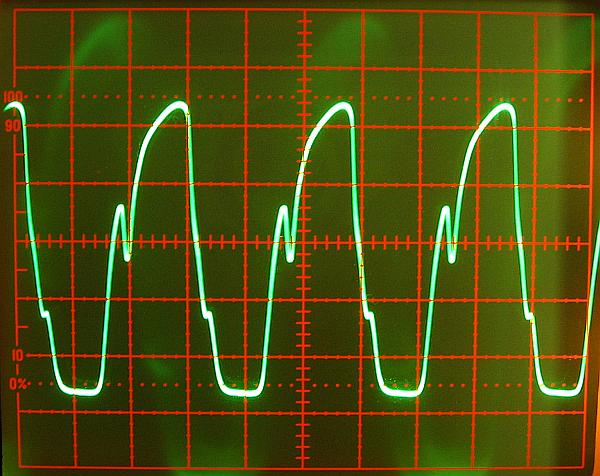
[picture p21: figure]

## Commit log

2022-09-09 first commit before proto
    [Ampli_0_5W-B_Cu.gbl, Ampli_0_5W-B_Mask.gbs, Ampli_0_5W-B_Paste.gbp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]
2022-09-09 picture and pdf schematic added
2022-09-18 release 2.0, shorter drain path
    [Ampli_0_5W-B_Cu.gbl, Ampli_0_5W-B_Paste.gbp, Ampli_0_5W-B_Silkscreen.gbo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]
2022-09-27 shorten drain circuit, new gerber, new ibom
    [Ampli_0_5W-B_Cu.gbl, Ampli_0_5W-B_Mask.gbs, Ampli_0_5W-B_Paste.gbp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]
2022-10-12 PCB V2 final
2023-02-12 Diomedes V1.0 final with correct psu, bias & drain trace
    [Ampli_0_5W.kicad_pcb, Ampli_0_5W.kicad_sch]
2023-02-12 new V1.0 Gerber, new ReadMe
    [Ampli_0_5W-B_Cu.gbl, Ampli_0_5W-B_Mask.gbs, Ampli_0_5W-B_Paste.gbp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]
2023-02-12 Diomedes V2.0 final, bias OK
    [Ampli_0_5W-B_Cu.gbl, Ampli_0_5W-B_Mask.gbs, Ampli_0_5W-B_Paste.gbp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]
2023-02-14 new ibom, BEWARE, KICAD 7.0 FILE FORMAT
    [Ampli_0_5W.kicad_pcb, Ampli_0_5W.kicad_sch]
2023-02-14 Kicad 7, new iBom, new temp diode cabling
    [Ampli_0_5W-B_Cu.gbl, Ampli_0_5W-B_Mask.gbs, Ampli_0_5W-B_Paste.gbp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]
2023-02-14 temp diode 3D model modified, new ibom new gerber
    [Ampli_0_5W.kicad_pcb]
2023-02-17 pennywhistle compatible mounting holes
    [Ampli_0_5W.kicad_pcb, Ampli_0_5W.kicad_sch]
2023-02-17 new 3D image, minor changes
    [Ampli_0_5W.kicad_pcb, Ampli_0_5W.kicad_sch, BN 73-202.STEP]
2023-02-17 new pdf schematic with dual BJT transistor
2023-03-31 new slotted pcb, new transistor added
    [Ampli_0_5W-B_Cu.gbl, Ampli_0_5W-B_Mask.gbs, Ampli_0_5W-B_Paste.gbp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]
